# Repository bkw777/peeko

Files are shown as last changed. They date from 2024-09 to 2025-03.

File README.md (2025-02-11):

# PEEKO

Alternate PCB for [gusmanb/logicanalyzer](https://github.com/gusmanb/logicanalyzer)

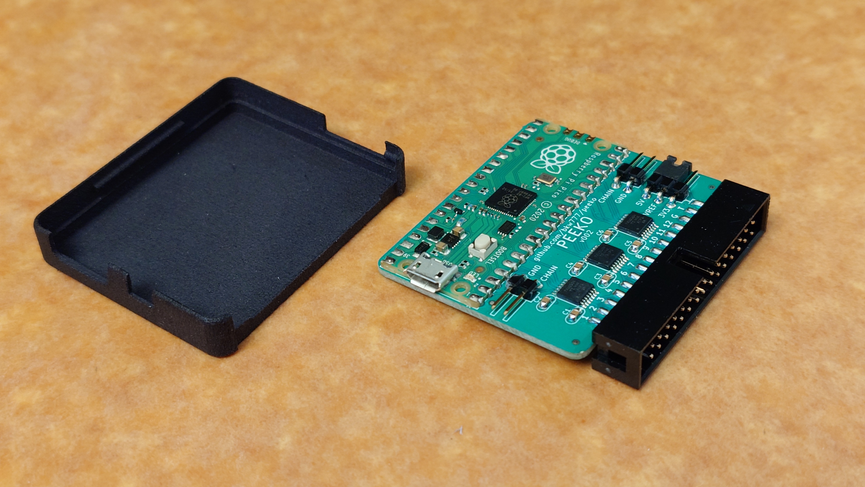
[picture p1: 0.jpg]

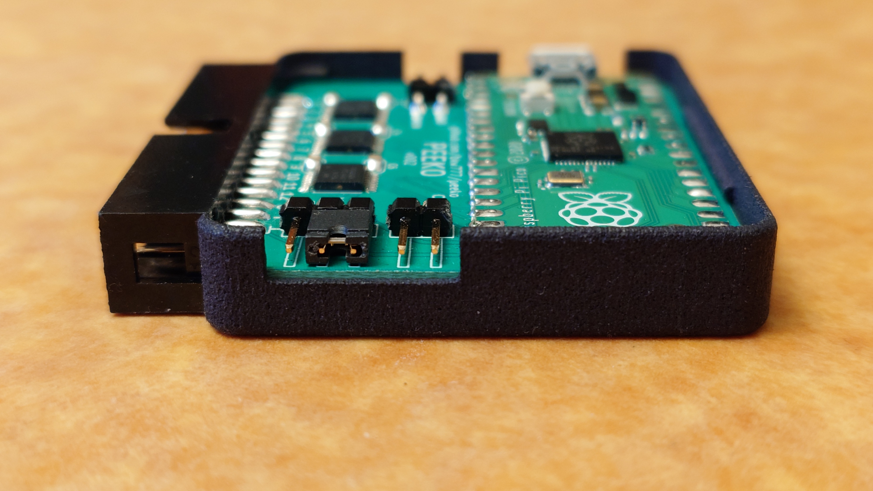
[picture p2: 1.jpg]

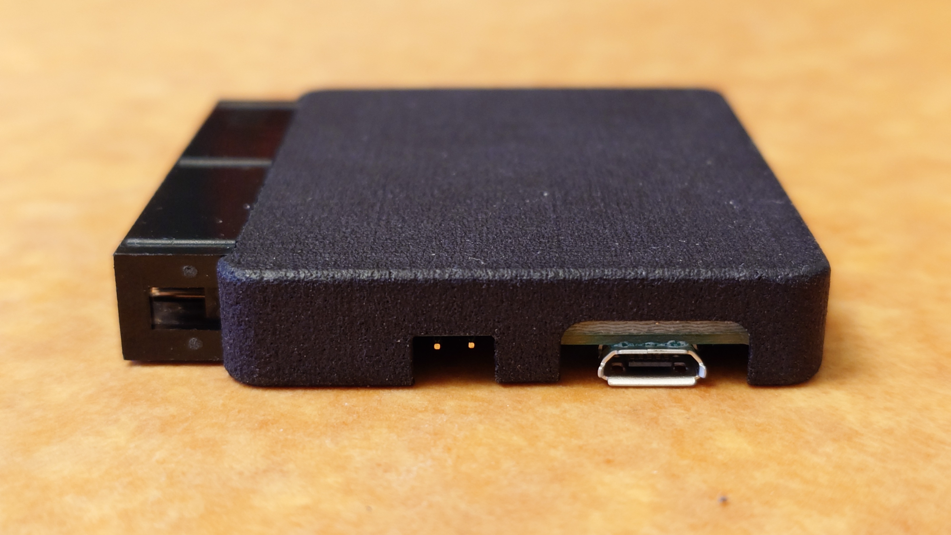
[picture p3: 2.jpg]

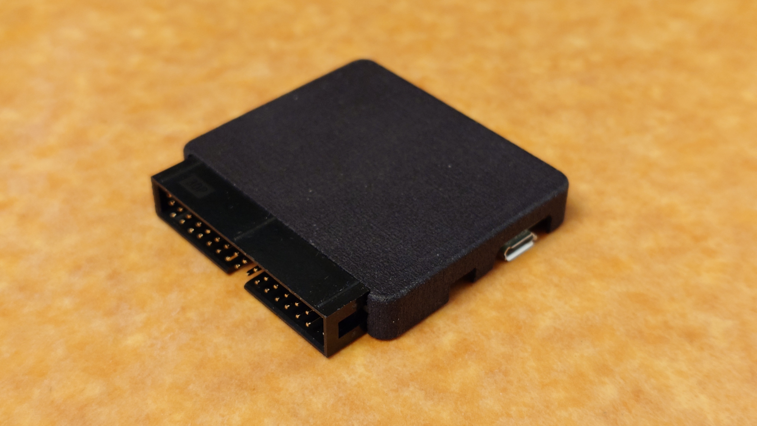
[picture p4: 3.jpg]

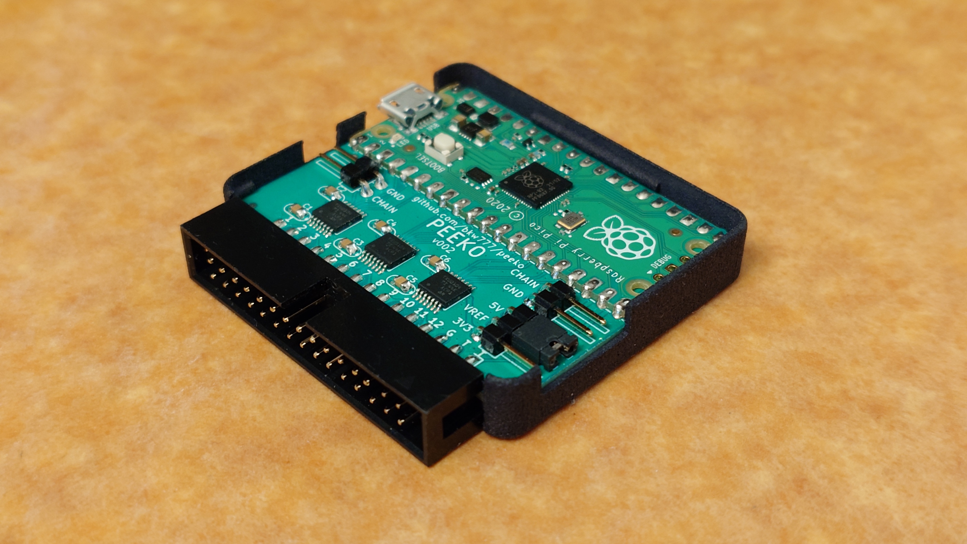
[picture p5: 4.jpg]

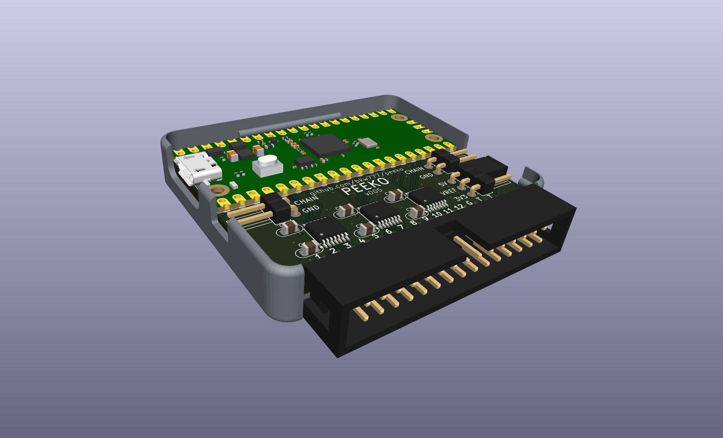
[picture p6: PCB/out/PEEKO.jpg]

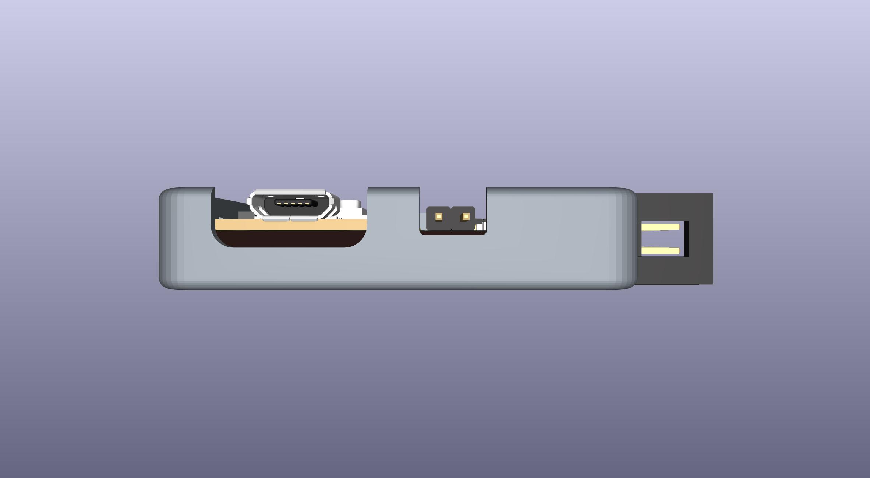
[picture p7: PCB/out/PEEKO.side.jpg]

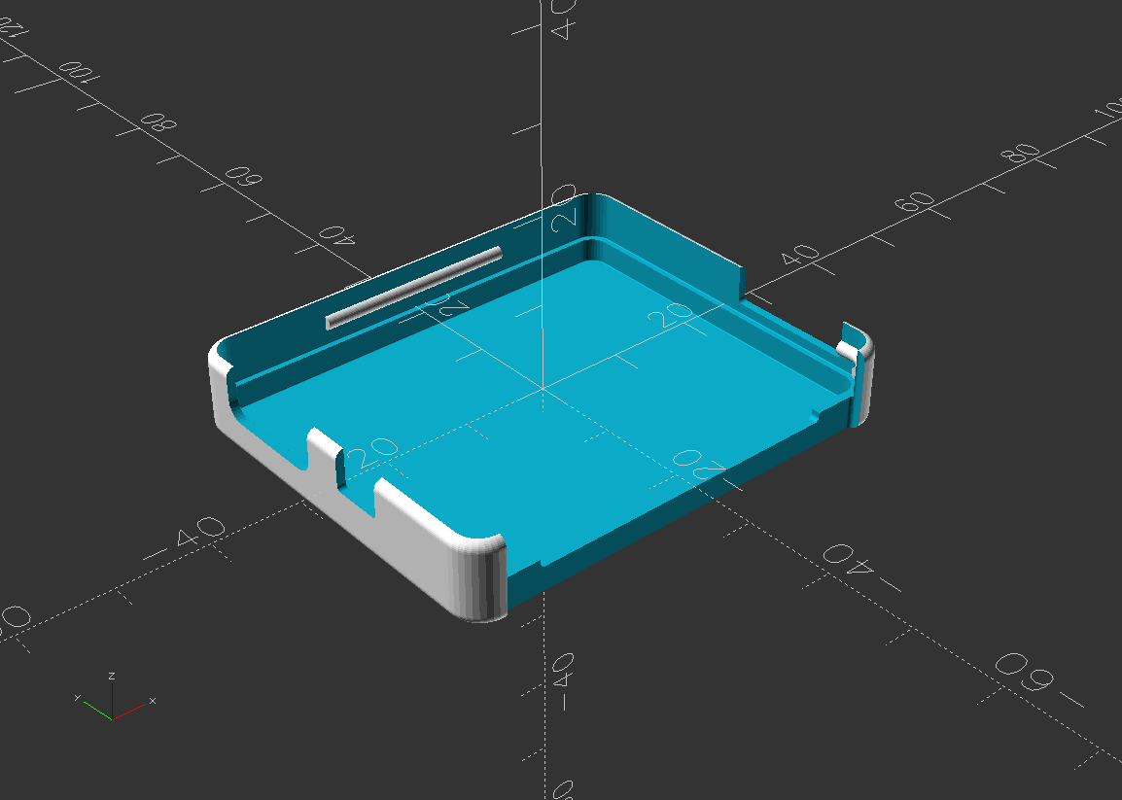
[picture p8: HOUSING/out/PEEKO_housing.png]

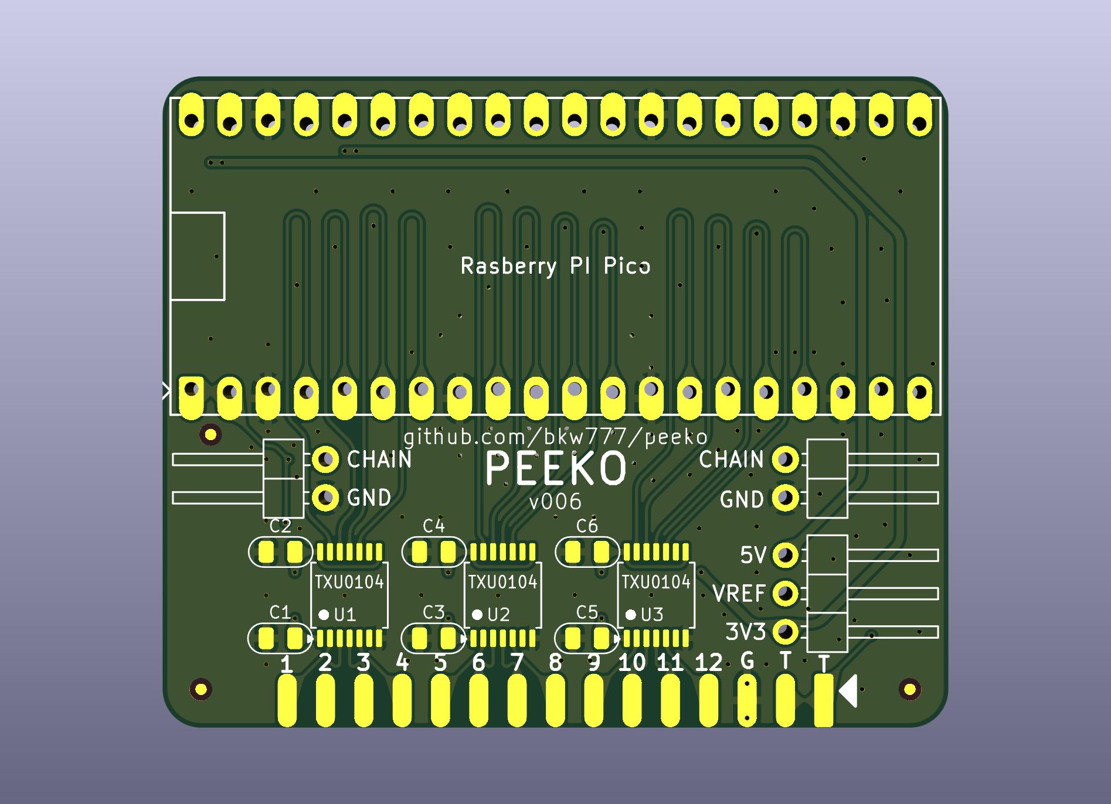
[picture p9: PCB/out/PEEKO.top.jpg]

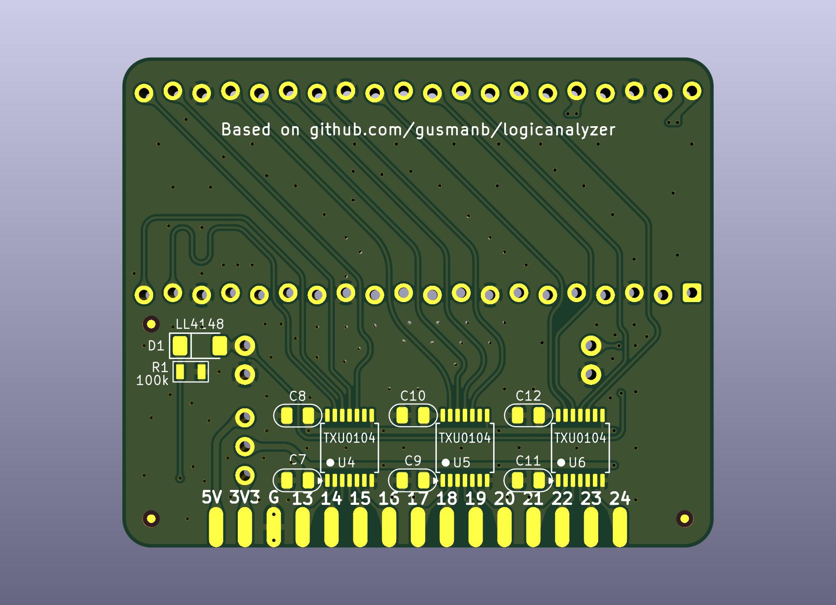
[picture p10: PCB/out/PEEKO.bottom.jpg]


[PEEKO.bom.csv](PCB/out/PEEKO.bom.csv)

# BOM

[DigiKey](https://www.digikey.com/short/h755hpzf)  ([PEEKO.bom.csv](PCB/out/PEEKO.bom.csv))

<!--
Alternate parts for chain:  
[header molex 2-pin male r/a](https://www.digikey.com/en/products/detail/molex/1718574002/5116867)  
[cable molex 2-pin female-female 150mm](https://www.digikey.com/en/products/detail/molex/2177961021/14637993)  
TODO:  
* Zigzag pico pin holes  
  so pico can be installed removable with only male pins soldered to the pico  
  this elevates the pico by the same amount as the molex pin headers over the plain pin headers (2.54mm)  
* Version of enclosure with 2.54mm taller walls  
* Lid to close up the enclosure, with opening for heat sink for overclocked pico2
* Printable legend for the input pins
-->

# PROBES

Cable: https://www.digikey.com/en/products/detail/digilent-inc/310-064/5848557

Mini-grabbers: [terrible](https://www.amazon.com/dp/B07BCZSNGS), [good](https://amazon.com/dp/B09TPBS7YF/147-7256223-7410705), [expensive](https://www.amazon.com/dp/B00R3R7IVC)

# FIRMWARE

Download *-PICO.uf2 from https://github.com/gusmanb/logicanalyzer/releases  
Hold BOOTSEL button while connecting usb.  
Drag *-PICO.uf2 onto the RPI-RP2 drive.

PICO will reboot itself immediately and RPI-RP2 drive will disappear. PEEKO is ready to use.

# USAGE

For software, firmware, & directions, see [gusmanb/logicanalyzer/wiki](https://github.com/gusmanb/logicanalyzer/wiki)

# Other Versions

Brute-force diode-clamping version: [brute-clamp](brute-clamp.md)

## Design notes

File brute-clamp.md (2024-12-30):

# PEEKO-Brute

Re-drawn version of the Jason Yang PCB from [gusmanb/logicanalyzer](https://github.com/gusmanb/logicanalyzer)

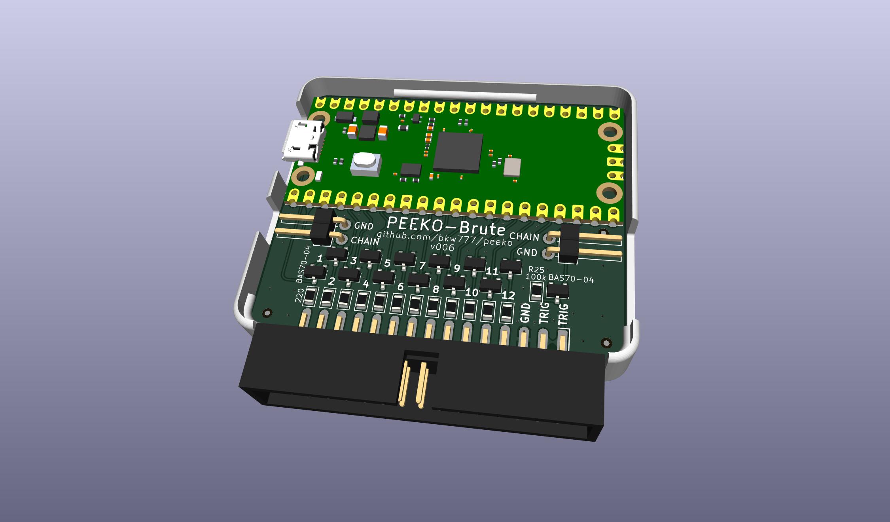
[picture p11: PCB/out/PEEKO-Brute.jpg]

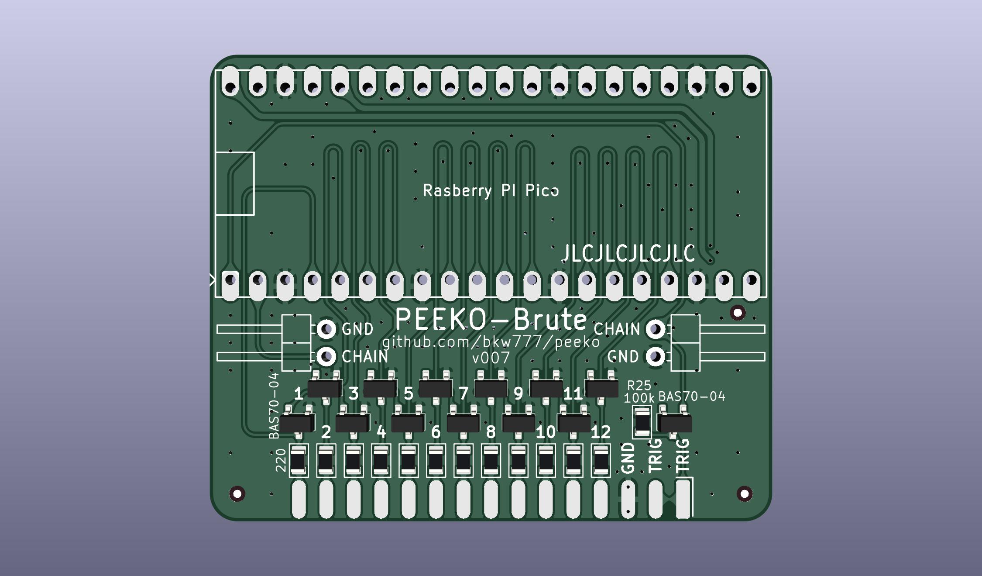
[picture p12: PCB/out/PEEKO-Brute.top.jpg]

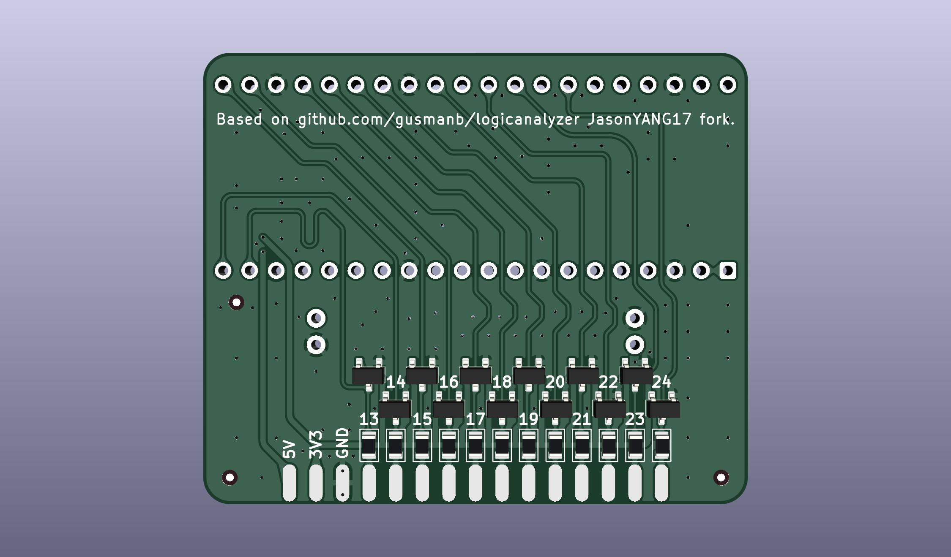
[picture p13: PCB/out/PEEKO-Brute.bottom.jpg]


[PEEKO-Brute.bom.csv](PCB/out/PEEKO-Brute.bom.csv)

# BOM
[DigiKey](https://www.digikey.com/short/7wdbdp9q)  ([PEEKO-Brute.bom.csv](PCB/out/PEEKO-Brute.bom.csv))

The housing is the regular PEEKO housing.

# Description

This is a re-drawn version of the Jason Yang board, which does level-shifting via diode-clamping.

This is pretty brute-force and pretty abusive to both the circuit under test and the PICO, but can also handle voltages much lower than 0v and much higher than 5v.

Changes vs the original:  
* simpler cleaner traces  
* schottky diodes
* 2-layer PCB  
* schematic
* KiCAD

The good thing about this is that it can handle levels below 0v and above 5v.

The bad thing about this is that it loads the circuit under test, *hard*.

For a 12v input signal, the Pico inputs will still be over-driven a little to almost 4v, and it will try to draw at least 36ma from the driver generating the signal.  
For -12v, the Pico input sees -0.5v and pulls around 50ma from the source.

Depending on what the circuit under test actually is, maybe this burns out the output drivers on some chips, or maybe they can handle it, or maybe the signal gets pulled down to 4v when the rest of the circuit expects 12v.

12v is an extreme example, and at 5v the numbers get smaller and better, but don't go away.

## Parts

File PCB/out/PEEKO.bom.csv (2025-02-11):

Reference | Value | Datasheet | Footprint | Qty | DNP | MPN | Description
C1,C2,C3,C4,C5,C6,C7,C8,C9,C10,C11,C12 | 100n | datasheets/UPY-GPHC_X7R_6.3V-to-250V_24.pdf | 000_LOCAL:C_0805 | 12 |  | CC0805KRX7R9BB104 | CAP CER 0.1UF 50V X7R 0805
D1 | LL4148 | datasheets/ll4148.pdf | 000_LOCAL:D_MiniMELF | 1 |  | FDLL4148 | 50V 1A General Purpose Rectifier Diode
J1 | Rasberry PI Pico | datasheets/rpi-pico.pdf | 000_LOCAL:dip-40-700-pi-pico | 1 |  | SC0915 | RASPBERRY PI PICO RP2040
J2 | Conn_02x15_Odd_Even | datasheets/SBH11.pdf | 000_LOCAL:IDC_02x15_2.54_THT_male_pcb_edge | 1 |  | SBH11-PBPC-D15-ST-BK | CONN HEADER VERT 30POS 2.54MM
J3,J4 | Conn_01x02_Pin | ~ | 000_LOCAL:PinHeader_1x02_P2.54mm_Horizontal | 2 |  | PH1RB-02-UA | CONN HEADER R/A 2POS 2.54MM
R1 | 100k | datasheets/PYu-RC_Group_51_RoHS_L_12.pdf | 000_LOCAL:R_0805 | 1 |  | RC0805FR-07100KL | RES 100K OHM 1% 1/8W 0805
U1,U2,U3,U4,U5,U6 | TXU0104 | datasheets/txu0104.pdf | 000_LOCAL:TSSOP-14_4.4x5mm_P0.65mm | 6 |  | TXU0104PW | 4-Bit Unidirectional Voltage-Level Translator, Schmitt trigger input, tri-state output, 1.1v to 5.5v, vTSSOP-14

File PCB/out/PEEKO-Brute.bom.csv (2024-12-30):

Reference | Value | Datasheet | Footprint | Qty | DNP | MPN
D1,D2,D3,D4,D5,D6,D7,D8,D9,D10,D11,D12,D13,D14,D15,D16,D17,D18,D19,D20,D21,D22,D23,D24,D25 | BAS70-04 | datasheets/INFNS30154-1.pdf | 000_LOCAL:SC-59 | 25 |  | BAS70-04
J1 | Rasberry PI Pico | datasheets/rpi-pico.pdf | 000_LOCAL:dip-40-700-pi-pico | 1 |  | SC0915
J2 | Conn_02x15_Odd_Even | datasheets/SBH11.pdf | 000_LOCAL:IDC_02x15_2.54_THT_male_pcb_edge | 1 |  | SBH11-PBPC-D15-ST-BK
J3,J4 | Conn_01x02_Pin | ~ | 000_LOCAL:PinHeader_1x02_P2.54mm_Horizontal | 2 |  | PH1RB-02-UA
R1,R2,R3,R4,R5,R6,R7,R8,R9,R10,R11,R12,R13,R14,R15,R16,R17,R18,R19,R20,R21,R22,R23,R24 | 220 | datasheets/TE-1-2176341-7.pdf | 000_LOCAL:R_0805 | 24 |  | CRGCQ0805F220R
R25 | 100k | datasheets/PYu-RC_Group_51_RoHS_L_12.pdf | 000_LOCAL:R_0805 | 1 |  | RC0805FR-07100KL

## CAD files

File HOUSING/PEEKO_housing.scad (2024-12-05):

/*
 * Housing for PEEKO
 */

// The brute board fits in the standard pico housing now.
model = "peeko";
//model = "brute";

mil = 0.0254;
//mw = 0.8; // minimum allowed wall thickness
fc = 0.1;   // fitment clearance 0.2 for FDM, 0.1 for SLS
e = 0.1;    // epsilon (overlap/overcut)
peeko = (model=="peeko")?true:false;
brute = (model=="brute")?true:false;


pcb_stl =
  (brute) ? "inc/PEEKO-Brute.stl":
            "inc/PEEKO.stl";

pcb_w = 2050*mil;   // X
pcb_d = 1700*mil;   // Y
pcb_h = 1.6;        // Z
pcb_r = 100*mil;    // corner radius

// 2.8 exactly protects Pico soldered directly to PCB
components_h = 2.8;

retainer_radius = 0.8;
ledge_width = 0.5; // ledge width
wt = 1;          // wall thickness
cr = 0.5;        // corner/fillet radius
er = fc+wt;      // external radius

// z=0 is the bottom surface of the pcb
above_ih = pcb_h + components_h;
below_ih = components_h;

//$fa = 2;
//$fs = 0.1;
$fn = 36;

ew = er+pcb_w+er;
ed = er+pcb_d+er;
ih = below_ih + above_ih;
above_eh = above_ih + er;
below_eh = below_ih + er;
eh = below_eh + above_eh;
lw = ledge_width + fc;


// =================================================================

use <inc/handy.scad>

module fit_parts() {
  import(pcb_stl);
}

module body () {
     difference() {

      // add
      // exterior
      translate([0,0,eh/2-below_eh])
       rounded_cube(w=ew,d=ed,h=eh,rh=pcb_r+er,rv=er,t=0);

      // cut
      union () {
        // pcb cavity (pcb length & width + fitment_clearance)
        translate([0,0,eh/2-fc])
         rounded_cube(w=fc+pcb_w+fc,d=fc+pcb_d+fc,h=eh,rh=pcb_r+fc,rv=fc,t=0);

        // bottom cavity (pcb length & width - ledge_width)
        // d is reduced and offset so that the wall behind the IDC
        // connector is wall-thickness thick after cutting away the pocket
        translate([0,wt-fc-fc/2-lw,ih/2-below_eh+wt])
         rounded_cube(w=pcb_w-lw*2,d=pcb_d-lw-wt-fc,h=ih,rh=pcb_r-lw,rv=er-wt,t=0);

        // idc
        _w = cr+45.628+cr;
        _d = 12;
        _h = cr+9.2+1+cr;
        translate([0,-pcb_d/2-_d/2+fc,pcb_h/2])
         rounded_cube(w=_w,d=_d,h=_h,rh=cr,rv=cr,t=0);
        translate([0,-pcb_d/2-_d/2+lw+cr+1,pcb_h/2])
         rounded_cube(w=1450*mil,d=_d,h=150*mil,rh=cr,rv=cr,t=0);

        // usb
        uw = cr+8+cr;
        ud = 14;
        uh = 8;
        uy = 470*mil; // pcb edge to usb center
        translate([-pcb_w/2,pcb_d/2-uy,pcb_h+2.4])
         rounded_cube(w=uw,d=ud,h=uh,rh=2,rv=2,t=0);

        // chain
        cx = 650*mil; // pcb edge to pin header center
        x = fc+wt+cr+e;
        pz = eh/2+pcb_h-cr;
        translate([0,-pcb_d/2+cx,pz])
          rounded_cube(d=cr+200*mil+cr,w=x+pcb_w+x,h=eh,rh=cr,rv=cr,t=0);

        if (peeko) {

        // vref
        vx = 350*mil; // pcb edge to pin center
        ve = 4; // extra width on opne side to join with other hole
        vd = cr+300*mil+cr +ve;
        translate([pcb_w/2+fc,-pcb_d/2+vx +ve/2,pz])
          rounded_cube(w=cr+1+wt*2+1+cr,d=vd,h=eh,rh=cr,rv=cr,t=0);

        } // if (peeko)

        // debugging cutaway
        //translate([0,ed/4+e/2,eh/2-below_eh-wt-e]) cube([e+ew+e,ed/2+e,e+eh+e],center=true);

      }
    }
    
    // retainers
    rl = 30; // long cylinder in rear wall
    rs = (brute) ? 6 : 2.1 ; // short cylinders at front corners
    rr = retainer_radius;
    rz = pcb_h+rr+fc;
    thr = pcb_r+fc; // torus horizontal radius

    mirror_copy([1,0,0]) {
      // short cylinders in front corners
      translate([pcb_w/2+fc,-pcb_d/2+pcb_r+rs/2-e,rz])
        rotate([90,0,0])
          cylinder(h=rs,r=rr,center=true);
      // 1/4 torus in front corners
      translate([-pcb_w/2-fc+thr,-pcb_d/2-fc+thr,rz])
      rotate([0,0,180])
      intersection() {
        translate([0,0,-thr]) cube(thr*2);
        torus(rh=thr,rv=rr);
      }
    }

    // long cylinder in rear wall
    translate([0,pcb_d/2+fc,rz])
      rotate([0,90,0])
        cylinder(h=pcb_w/2-pcb_r,r=rr,center=true);

}

// =================================================================

%fit_parts();
body();

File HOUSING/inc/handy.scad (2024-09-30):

// b.kenyon.w@gmail.com - handy box
// fillets and handy things made from fillets

/*
   screw_post(h=10,od=6,id=3,fr=2,ch=0,o=0)

     cylindrical screw post with filleted base

     h = height
     od = main cylinder OD
     id = screw hole ID - default no hole
     fr = base fillet radius
     ch = screw hole chamfer depth - default no chamfer
     o = fillet ID shrink offset - usually unset

   rounded_cube(w=60,d=40,h=20,rh=2,rv=1,t=0)

     draws a cube with rounded corners

     w = width
     d = depth
     h = height
     rh = horizontal radius
     rv = vertical radius
     t = wall thickness - if set, makes a hollow box

   fillet_polar(o=false,R=1,r=1,A=90,a=90,as=0)

     creates both internal and external radial fillets
     used to create screw_post() and rounded_cube()
  
     o = outside true/false - default false (inside/concave)
     R = big radius
     r = small radius
     A = big angle
     a = small angle
     as = small angle start angle

   fillet_linear(o=false,l=1,r=1,a=90)
   
     o = outside - true/false - default false (inside/concave)
     l = length
     r = radius
     a = angle

*/

//$fs = 0.5;
//$fa = 1;
//$fn = 96;
//$fn = 72;
//$fn = 36;
//$fn = 12;

// examples:
//translate([60,0,0]) screw_post(h=10,od=6,id=3,fr=2,ch=0.6);
//difference() { rounded_cube(w=70,d=55,h=25,rh=3,rv=1,t=2); translate([0,-40,0]) cube([40,40,20]); }
//difference() { rounded_cube(w=70,d=55,h=25,rh=3,rv=1); translate([0,-40,0]) cube([40,40,20]); }
//fillet_linear(l=40);
//fillet_polar(R=2,r=1);

module screw_post(h=10,od=6,id=0,fr=2,o=0,ch=0) {
 x = (o) ? o : ($fn>=3) ? 0 : 0.025;
 difference() {
  union(){
   translate([0,0,h/2]) cylinder(h=h,d=od,center=true);
   translate([0,0,fr+x]) fillet_polar(R=-od/2+x,r=fr+x,A=360,as=90);
  }
  if(id>0) {
   translate([0,0,h/2]) cylinder(h=h+0.1,d=id,center=true);
   if(ch) translate([0,0,h-id/2-ch]) cylinder(h=od/2,d1=0,d2=od);
  }
 }
}

module rounded_cube(w=60,d=40,h=20,rh=2,rv=1,t=0) {
  _w=t+w+t;
  _d=t+d+t;
  _h=t+h+t;
  if (rh==0&&rv==0) {
    // plain cube
    if(t) difference() {
      cube([_w,_d,_h],center=true);
      cube([w,d,h],center=true);
    }
    else cube([w,d,h],center=true);
  }
  else if (rv==0) {
    // rounded plate
    if(t) difference() {
      _hbrp(w=_w,d=_d,h=_h,r=rh+t);
      _hbrp(w=w,d=d,h=h,r=rh);
    }
    else _hbrp(w=w,d=d,h=h,r=rh);
  } else {
    // rounded cube
    if(t) difference() {
      _hbrc(w=_w,d=_d,h=_h,rh=rh+t,rv=rv+t);
      _hbrc(w=w,d=d,h=h,rh=rh,rv=rv);
    }
  else _hbrc(w=w,d=d,h=h,rh=rh,rv=rv);
  }
}

module _hbrc(w=60,d=40,h=20,rh=2,rv=1) { // rounded cube
 hull() {
  mirror_copy([0,0,1])
   mirror_copy([0,1,0])
    mirror_copy([1,0,0])
     translate([w/2-rh,d/2-rh,h/2-rv])
      fillet_polar(o=true,R=rh,r=rv);
 }
}

module _hbrp(w=60,d=40,h=20,r=2) { // rounded plate
 hull() {
   mirror_copy([0,1,0])
    mirror_copy([1,0,0])
     translate([w/2-r,d/2-r,-h/2])
      fillet_linear(o=true,l=h,r=r,a=90);
 }
}

module fillet_polar(o=false,R=1,r=1,A=90,a=90,as=0) {
 rotate_extrude(angle=A)
  translate([R-r,0,0])
   rotate([0,0,-as])
    _hbf(o,r,a);
}

module fillet_linear(o=false,l=1,r=1,a=90) {
 linear_extrude(height=l,center=false)
  _hbf(o,r,a);
}

module _hbf(o=false,r=1,a=90) { // 2d fillet
 if(o) intersection() { circle(r=r); _hbw(r=r,a=a); }
 else difference() { _hbw(r=r,a=a); circle(r=r); }
}

module _hbw (r=1,a=90) { // 2d wedge polygon
  polygon([ [0,0], [0,r], [r*tan(a/2),r], [r*sin(a),r*cos(a)] ]);
}

module mirror_copy(v) {
 children();
 mirror(v) children();
}

module xy_array(xo=10,xc=4,yo=10,yc=2,center=false) {
 xe = (xc-1)*xo;
 ye = (yc-1)*yo;
 tx = center ? -xe/2 : 0;
 ty = center ? -ye/2 : 0;
 translate([tx,ty,0])
 for (i=[0:xo:xe]) {
  for (j=[0:yo:ye]) {
    translate([i,j,0])
     children();
  }
 }
}

module torus(rh=10,rv=1)
{
  rotate_extrude(convexity=10)
    translate([rh,0,0])
      circle(r=rv);
}

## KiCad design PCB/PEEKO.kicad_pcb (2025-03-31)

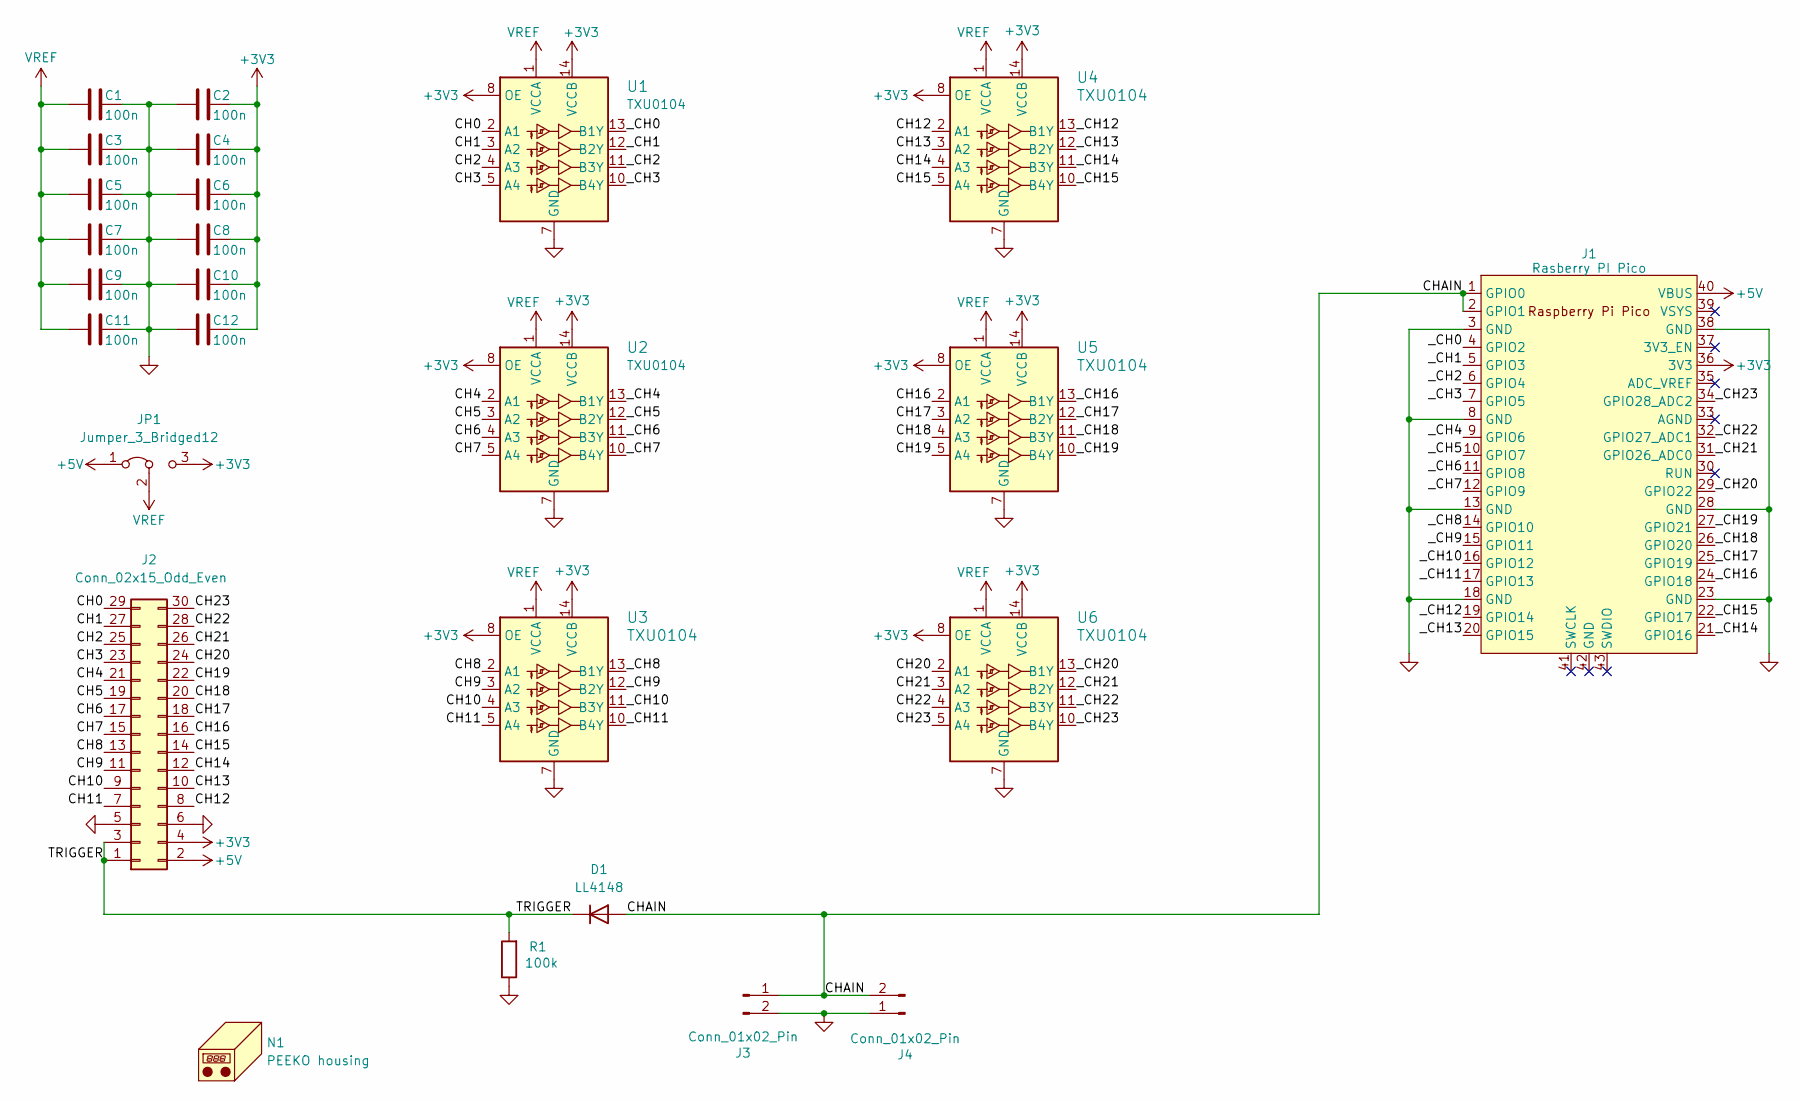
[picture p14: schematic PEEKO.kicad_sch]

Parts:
C1, C2, C3, C4, C5, C6, C7, C8, C9, C10, C11, C12: 100n; C_0805; MPN CC0805KRX7R9BB104
D1: LL4148; D_MiniMELF; MPN FDLL4148
J1: Rasberry PI Pico; dip-40-700-pi-pico-z; MPN SC0915
J2: Conn_02x15_Odd_Even; IDC_02x15_2.54_THT_male_pcb_edge; MPN SBH11-PBPC-D15-ST-BK
J3, J4: Conn_01x02_Pin; PinHeader_1x02_P2.54mm_Horizontal; MPN PH1RB-02-UA
JP1: Jumper_3_Bridged12; PinHeader_1x03_P2.54mm_Horizontal jumper 1-2; MPN PH1RB-03-UA
N1: PEEKO housing; PEEKO_housing
R1: 100k; R_0805; MPN RC0805FR-07100KL
U1, U2, U3, U4, U5, U6: TXU0104; TSSOP-14_4.4x5mm_P0.65mm; MPN TXU0104PW

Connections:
+3V3: C2.1, C4.1, C6.1, C8.1, C10.1, C12.1, J1.36 (3V3), J2.4, JP1.3 (B), U1.8 (OE), U1.14 (VCCB), U2.8 (OE), U2.14 (VCCB), U3.8 (OE), U3.14 (VCCB), U4.8 (OE), U4.14 (VCCB), U5.8 (OE), U5.14 (VCCB), U6.8 (OE), U6.14 (VCCB)
+5V: J1.40 (VBUS), J2.2, JP1.1 (A)
/CH0: J2.29, U1.2 (A1)
/CH1: J2.27, U1.3 (A2)
/CH2: J2.25, U1.4 (A3)
/CH3: J2.23, U1.5 (A4)
/CH4: J2.21, U2.2 (A1)
/CH5: J2.19, U2.3 (A2)
/CH6: J2.17, U2.4 (A3)
/CH7: J2.15, U2.5 (A4)
/CH8: J2.13, U3.2 (A1)
/CH9: J2.11, U3.3 (A2)
/CH10: J2.9, U3.4 (A3)
/CH11: J2.7, U3.5 (A4)
/CH12: J2.8, U4.2 (A1)
/CH13: J2.10, U4.3 (A2)
/CH14: J2.12, U4.4 (A3)
/CH15: J2.14, U4.5 (A4)
/CH16: J2.16, U5.2 (A1)
/CH17: J2.18, U5.3 (A2)
/CH18: J2.20, U5.4 (A3)
/CH19: J2.22, U5.5 (A4)
/CH20: J2.24, U6.2 (A1)
/CH21: J2.26, U6.3 (A2)
/CH22: J2.28, U6.4 (A3)
/CH23: J2.30, U6.5 (A4)
/CHAIN: D1.2 (A), J1.1 (GPIO0), J1.2 (GPIO1), J3.1, J4.2
/TRIGGER: D1.1 (K), J2.1, J2.3, R1.2
/_CH0: J1.4 (GPIO2), U1.13 (B1Y)
/_CH1: J1.5 (GPIO3), U1.12 (B2Y)
/_CH2: J1.6 (GPIO4), U1.11 (B3Y)
/_CH3: J1.7 (GPIO5), U1.10 (B4Y)
/_CH4: J1.9 (GPIO6), U2.13 (B1Y)
/_CH5: J1.10 (GPIO7), U2.12 (B2Y)
/_CH6: J1.11 (GPIO8), U2.11 (B3Y)
/_CH7: J1.12 (GPIO9), U2.10 (B4Y)
/_CH8: J1.14 (GPIO10), U3.13 (B1Y)
/_CH9: J1.15 (GPIO11), U3.12 (B2Y)
/_CH10: J1.16 (GPIO12), U3.11 (B3Y)
/_CH11: J1.17 (GPIO13), U3.10 (B4Y)
/_CH12: J1.19 (GPIO14), U4.13 (B1Y)
/_CH13: J1.20 (GPIO15), U4.12 (B2Y)
/_CH14: J1.21 (GPIO16), U4.11 (B3Y)
/_CH15: J1.22 (GPIO17), U4.10 (B4Y)
/_CH16: J1.24 (GPIO18), U5.13 (B1Y)
/_CH17: J1.25 (GPIO19), U5.12 (B2Y)
/_CH18: J1.26 (GPIO20), U5.11 (B3Y)
/_CH19: J1.27 (GPIO21), U5.10 (B4Y)
/_CH20: J1.29 (GPIO22), U6.13 (B1Y)
/_CH21: J1.31 (GPIO26_ADC0), U6.12 (B2Y)
/_CH22: J1.32 (GPIO27_ADC1), U6.11 (B3Y)
/_CH23: J1.34 (GPIO28_ADC2), U6.10 (B4Y)
GND: C1.1, C2.2, C3.1, C4.2, C5.1, C6.2, C7.1, C8.2, C9.1, C10.2, C11.1, C12.2, J1.3 (GND), J1.8 (GND), J1.13 (GND), J1.18 (GND), J1.23 (GND), J1.28 (GND), J1.38 (GND), J2.5, J2.6, J3.2, J4.1, R1.1, U1.7 (GND), U2.7 (GND), U3.7 (GND), U4.7 (GND), U5.7 (GND), U6.7 (GND)
VREF: C1.2, C3.2, C5.2, C7.2, C9.2, C11.2, JP1.2 (C), U1.1 (VCCA), U2.1 (VCCA), U3.1 (VCCA), U4.1 (VCCA), U5.1 (VCCA), U6.1 (VCCA)

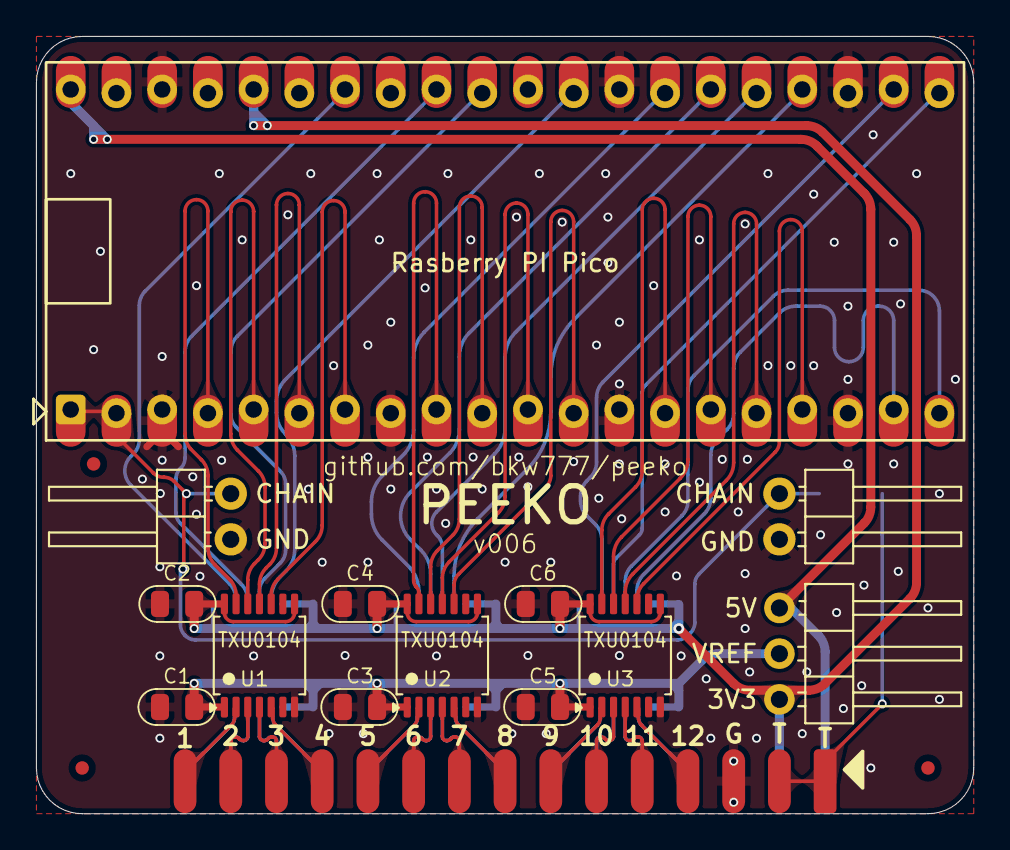
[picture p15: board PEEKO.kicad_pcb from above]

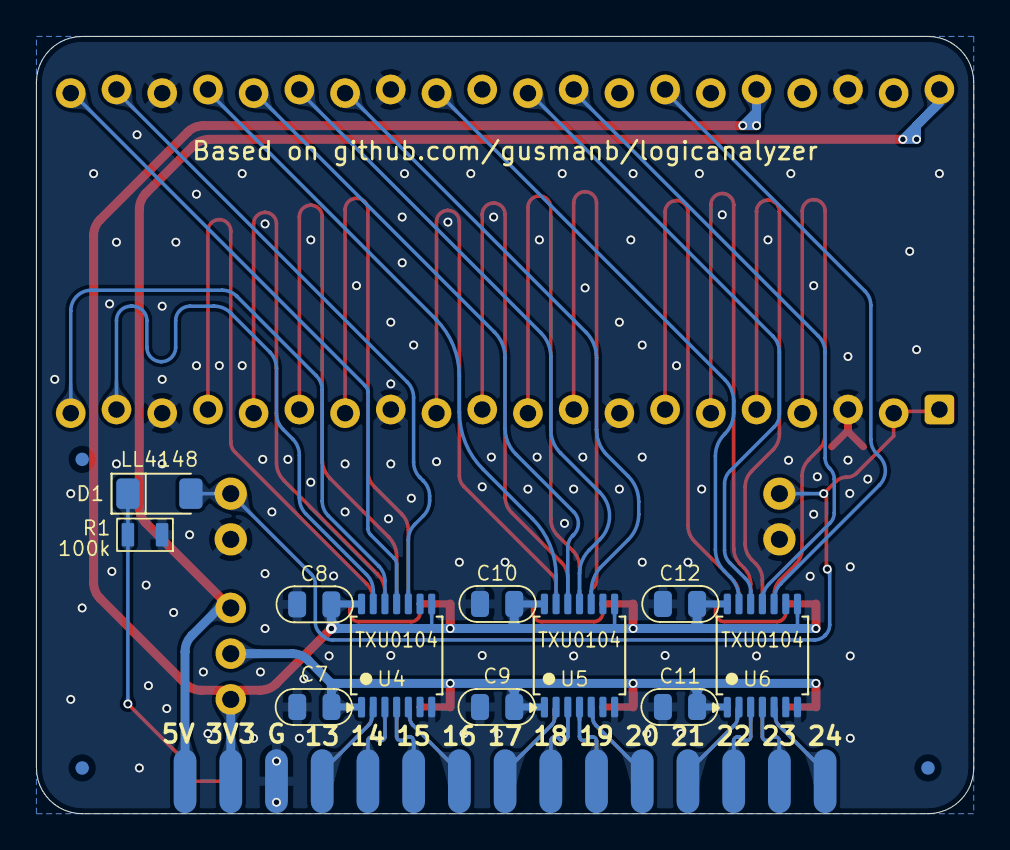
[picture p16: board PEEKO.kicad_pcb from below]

Board: 2 copper layers, 52.1 x 43.2 mm, 26 parts (11 on the bottom side), 54 nets.

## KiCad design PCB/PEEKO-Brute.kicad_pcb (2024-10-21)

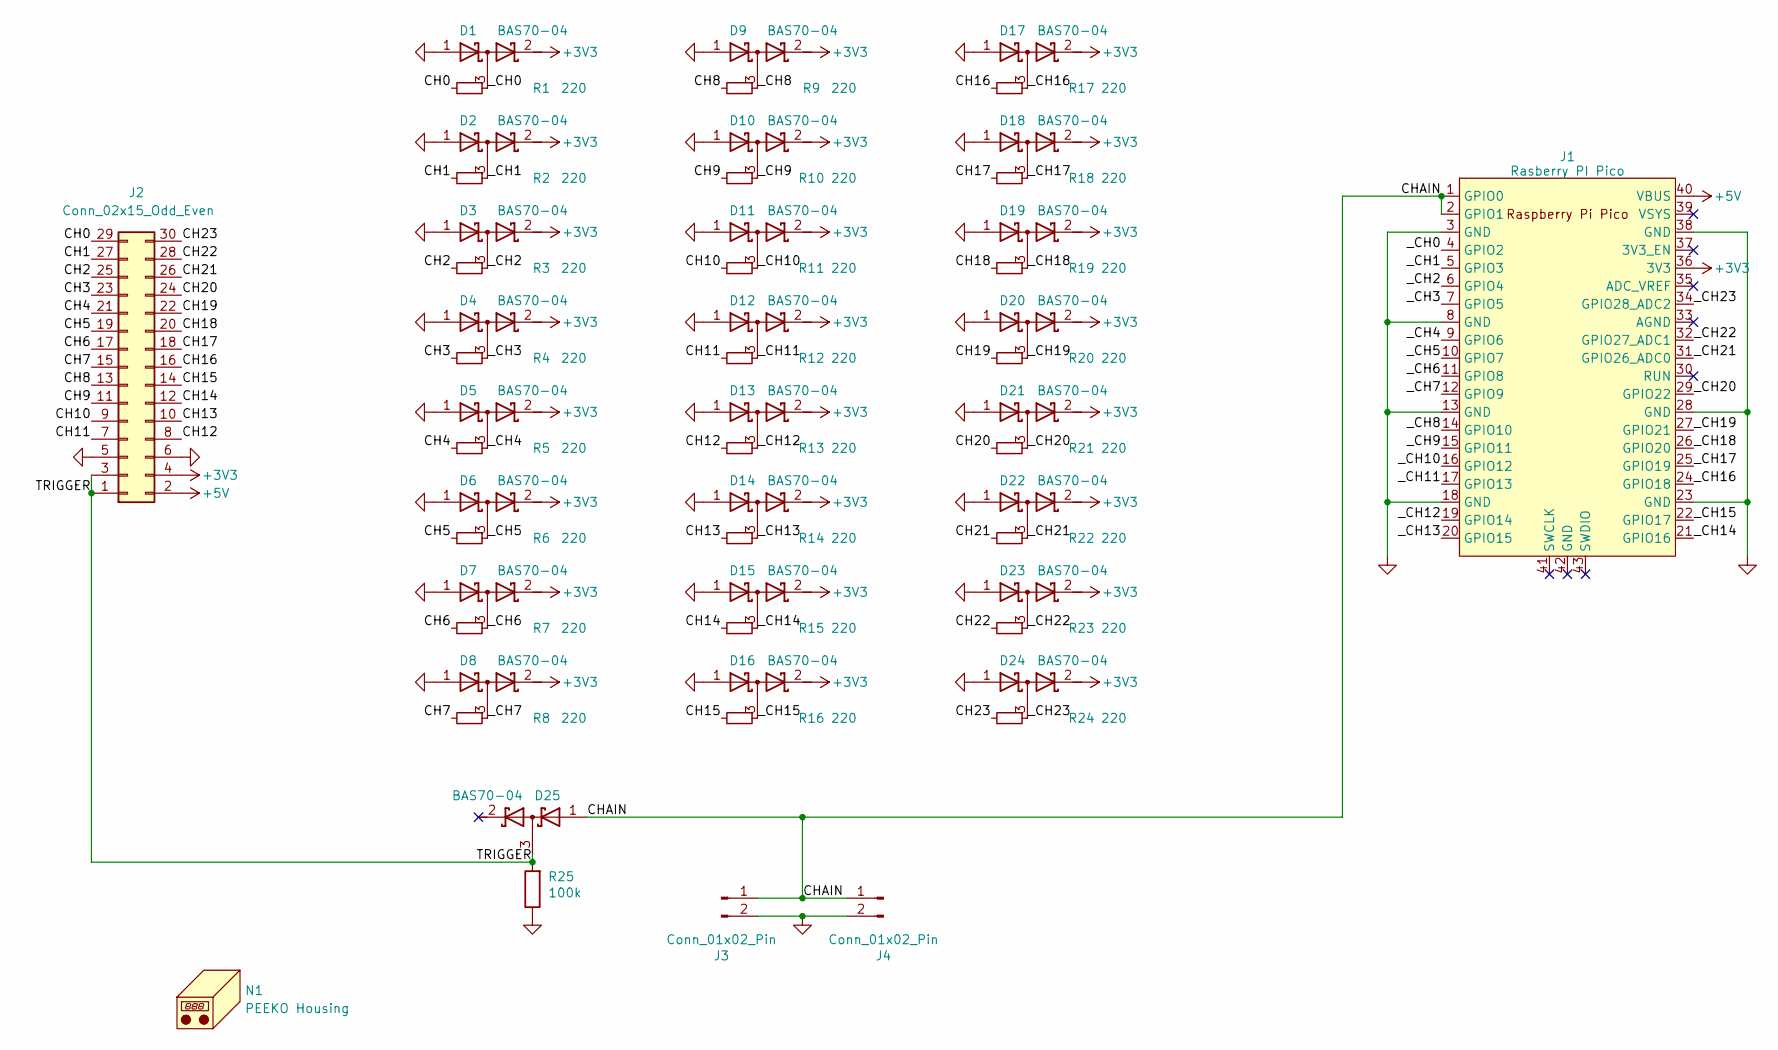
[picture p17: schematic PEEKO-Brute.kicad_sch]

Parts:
D1, D2, D3, D4, D5, D6, D7, D8, D9, D10, D11, D12, D13, D14, D15, D16, D17, D18, D19, D20, D21, D22, D23, D24, D25: BAS70-04; SC-59
J1: Rasberry PI Pico; dip-40-700-pi-pico; MPN SC0915
J2: Conn_02x15_Odd_Even; IDC_02x15_2.54_THT_male_pcb_edge; MPN SBH11-PBPC-D15-ST-BK
J3, J4: Conn_01x02_Pin; PinHeader_1x02_P2.54mm_Horizontal; MPN PH1RB-02-UA
N1: PEEKO Housing; PEEKO_housing
R1, R2, R3, R4, R5, R6, R7, R8, R9, R10, R11, R12, R13, R14, R15, R16, R17, R18, R19, R20, R21, R22, R23, R24: 220; R_0805; MPN CRGCQ0805F220R
R25: 100k; R_0805; MPN RC0805FR-07100KL

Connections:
+3V3: D1.2 (K), D2.2 (K), D3.2 (K), D4.2 (K), D5.2 (K), D6.2 (K), D7.2 (K), D8.2 (K), D9.2 (K), D10.2 (K), D11.2 (K), D12.2 (K), D13.2 (K), D14.2 (K), D15.2 (K), D16.2 (K), D17.2 (K), D18.2 (K), D19.2 (K), D20.2 (K), D21.2 (K), D22.2 (K), D23.2 (K), D24.2 (K), J1.36 (3V3), J2.4
+5V: J1.40 (VBUS), J2.2
/CH0: J2.29, R1.2
/CH1: J2.27, R2.2
/CH2: J2.25, R3.2
/CH3: J2.23, R4.2
/CH4: J2.21, R5.2
/CH5: J2.19, R6.2
/CH6: J2.17, R7.2
/CH7: J2.15, R8.2
/CH8: J2.13, R9.2
/CH9: J2.11, R10.2
/CH10: J2.9, R11.2
/CH11: J2.7, R12.2
/CH12: J2.8, R13.2
/CH13: J2.10, R14.2
/CH14: J2.12, R15.2
/CH15: J2.14, R16.2
/CH16: J2.16, R17.2
/CH17: J2.18, R18.2
/CH18: J2.20, R19.2
/CH19: J2.22, R20.2
/CH20: J2.24, R21.2
/CH21: J2.26, R22.2
/CH22: J2.28, R23.2
/CH23: J2.30, R24.2
/CHAIN: D25.1 (A), J1.1 (GPIO0), J1.2 (GPIO1), J3.1, J4.1
/TRIGGER: D25.3 (common), J2.1, J2.3, R25.2
/_CH0: D1.3 (common), J1.4 (GPIO2), R1.1
/_CH1: D2.3 (common), J1.5 (GPIO3), R2.1
/_CH2: D3.3 (common), J1.6 (GPIO4), R3.1
/_CH3: D4.3 (common), J1.7 (GPIO5), R4.1
/_CH4: D5.3 (common), J1.9 (GPIO6), R5.1
/_CH5: D6.3 (common), J1.10 (GPIO7), R6.1
/_CH6: D7.3 (common), J1.11 (GPIO8), R7.1
/_CH7: D8.3 (common), J1.12 (GPIO9), R8.1
/_CH8: D9.3 (common), J1.14 (GPIO10), R9.1
/_CH9: D10.3 (common), J1.15 (GPIO11), R10.1
/_CH10: D11.3 (common), J1.16 (GPIO12), R11.1
/_CH11: D12.3 (common), J1.17 (GPIO13), R12.1
/_CH12: D13.3 (common), J1.19 (GPIO14), R13.1
/_CH13: D14.3 (common), J1.20 (GPIO15), R14.1
/_CH14: D15.3 (common), J1.21 (GPIO16), R15.1
/_CH15: D16.3 (common), J1.22 (GPIO17), R16.1
/_CH16: D17.3 (common), J1.24 (GPIO18), R17.1
/_CH17: D18.3 (common), J1.25 (GPIO19), R18.1
/_CH18: D19.3 (common), J1.26 (GPIO20), R19.1
/_CH19: D20.3 (common), J1.27 (GPIO21), R20.1
/_CH20: D21.3 (common), J1.29 (GPIO22), R21.1
/_CH21: D22.3 (common), J1.31 (GPIO26_ADC0), R22.1
/_CH22: D23.3 (common), J1.32 (GPIO27_ADC1), R23.1
/_CH23: D24.3 (common), J1.34 (GPIO28_ADC2), R24.1
GND: D1.1 (A), D2.1 (A), D3.1 (A), D4.1 (A), D5.1 (A), D6.1 (A), D7.1 (A), D8.1 (A), D9.1 (A), D10.1 (A), D11.1 (A), D12.1 (A), D13.1 (A), D14.1 (A), D15.1 (A), D16.1 (A), D17.1 (A), D18.1 (A), D19.1 (A), D20.1 (A), D21.1 (A), D22.1 (A), D23.1 (A), D24.1 (A), J1.3 (GND), J1.8 (GND), J1.13 (GND), J1.18 (GND), J1.23 (GND), J1.28 (GND), J1.38 (GND), J2.5, J2.6, J3.2, J4.2, R25.1

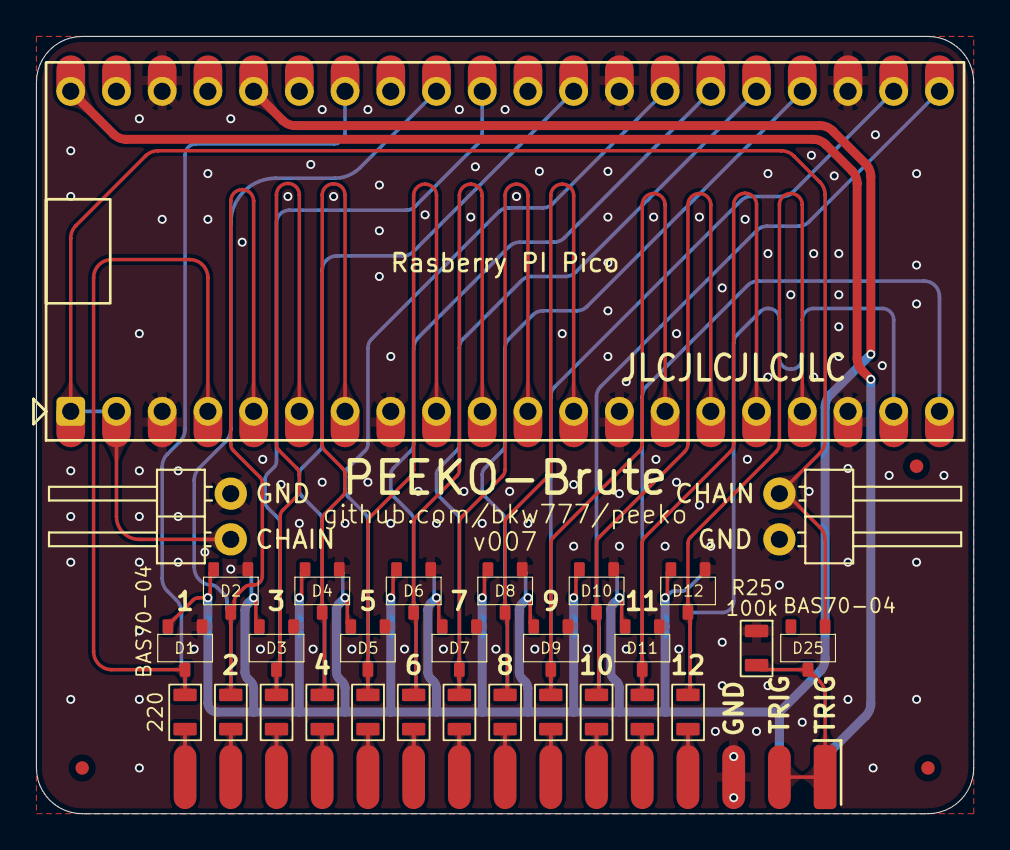
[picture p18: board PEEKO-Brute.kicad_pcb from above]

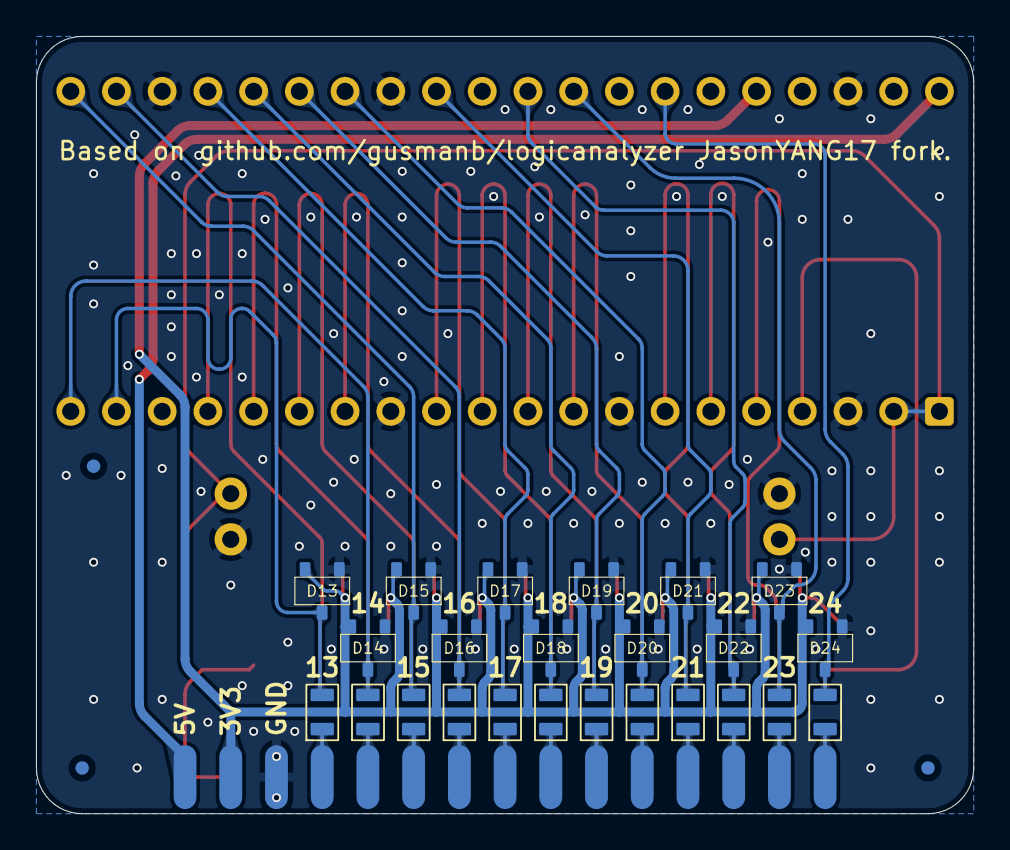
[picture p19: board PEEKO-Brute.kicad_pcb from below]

Board: 2 copper layers, 52.1 x 43.2 mm, 55 parts (24 on the bottom side), 53 nets.

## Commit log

2024-09-19 redraw main & jasonyang boards
    [AnalyzerBoxPCB_fork.kicad_pcb, AnalyzerBoxPCB_fork.kicad_sch, LevelShifter.dsn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]
2024-09-19 indiscriminate gitignore
    [2024-09-11T213020.csv]
2024-09-20 level shifter
    [LevelShifter.kicad_pcb, LevelShifter.kicad_sch, peeko.kicad_pcb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]
2024-09-20 shrink level shifter
    [peeko_input_level_shifter.kicad_pcb, peeko_input_level_shifter.kicad_sch]
2024-09-20 renumber level shifter
    [peeko_input_level_shifter.kicad_pcb, peeko_input_level_shifter.kicad_sch]
2024-09-21 schematic for JY board, remove all but PCBs
    [AnalyzerBox.SLDPRT, AnalyzerBox.STL, AnalyzerBoxMain_fork.3mf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]
2024-09-21 jy sch tidy
    [peeko_jy.kicad_pcb, peeko_jy.kicad_sch]
2024-09-21 jy pcb teardrops
    [peeko_jy.kicad_pcb]
2024-09-22 bom & readme
    [peeko_and_level_shifter_digikey.bom.csv]
2024-09-23 fixup local symbols, footprints, models, move power traces inboard
    [peeko.kicad_pcb, peeko.kicad_sch]
2024-09-23 jy inner2 5v
    [peeko_jy.kicad_pcb]
2024-09-26 jy reduce from 4 layer to 2
    [peeko_housing.scad, peeko_jy.kicad_pcb]
2024-09-28 jy ground paths, jy housing
    [peeko_jy.kicad_pcb, peeko_jy_housing.scad]
2024-09-30 local tssop14 footprint, redo short side traces on peeko+ & level shifter
    [peeko+.kicad_pcb, peeko_input_level_shifter.kicad_pcb, peeko_input_level_shifter.kicad_sch]
2024-09-30 level shifter housing
    [peeko_input_level_shifter.kicad_pcb, peeko_input_level_shifter.stl, peeko_input_level_shifter_housing.scad]
2024-10-01 peeko+ housing render
    [peeko+.kicad_pcb, peeko+.kicad_sch]
2024-10-05 drop seperate level-shifter
    [2024-09-11T213020.csv, PEEKO-Brute.kicad_pcb, PEEKO-Brute.kicad_sch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]
2024-10-05 single scad model
    [PEEKO-Brute_housing.scad, PEEKO_housing.scad]
2024-10-05 add fab bom and centroid exports
    [PEEKO-Brute.kicad_pcb, PEEKO-Brute.kicad_sch, PEEKO.fab_bom.csv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]
2024-10-06 switch to schottkys on brute
    [PEEKO-Brute.DigiKey.bom.csv, PEEKO-Brute.kicad_pcb, PEEKO-Brute.kicad_sch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]
2024-10-06 local fiducial footprint
    [PEEKO.kicad_pcb]
2024-10-07 make brute the same dimensions and port placement as regular peeko, use same housing for both
    [PEEKO-Brute.kicad_pcb, PEEKO-Brute.kicad_sch, PEEKO_housing.scad]
2024-10-07 make both boards have same chain pinout
    [PEEKO-Brute.kicad_pcb, PEEKO-Brute.kicad_sch]
2024-10-07 sch label
    [PEEKO.kicad_sch]
2024-10-07 pics, elecrow assembly bom
    [PEEKO-Brute.kicad_pcb, PEEKO.Elecrow.BOM.xlsx, PEEKO.kicad_pcb]
2024-10-07 refill zone
    [PEEKO-Brute.kicad_pcb]
2024-10-21 forgotten fillet track on brute
    [PEEKO-Brute.kicad_pcb, PEEKO.kicad_pcb, PEEKO_housing.scad]
2024-12-05 silkscreen, readme, probe wires, enclosure wall behind pins
    [PEEKO.DigiKey.bom.csv, PEEKO.kicad_pcb, PEEKO_housing.scad]
2025-02-11 shorten chain trace, delete duplicate footprints
    [PEEKO.bom.csv, PEEKO.kicad_pcb, PEEKO.kicad_sch]
2025-03-31 zigzag pi pico dip pins for friction fit
    [PEEKO.kicad_pcb, PEEKO.kicad_sch]
